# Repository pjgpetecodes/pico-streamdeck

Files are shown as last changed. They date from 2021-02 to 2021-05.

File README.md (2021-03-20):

# Pico Producer

## About this Project

This project is an OBS Controller using a Raspberry Pi Pico and CircuitPython.

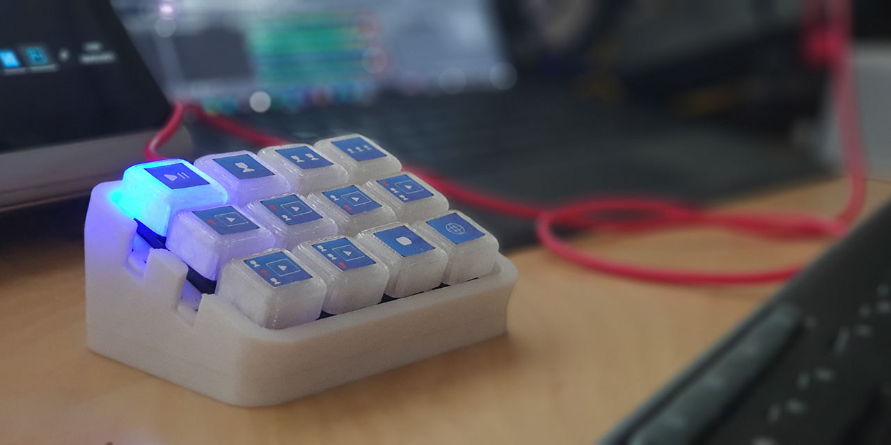
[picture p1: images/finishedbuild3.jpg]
Pico StreamDeck Build 1 Raspberry Pi Pico StreamDeck Build 1


# In Action

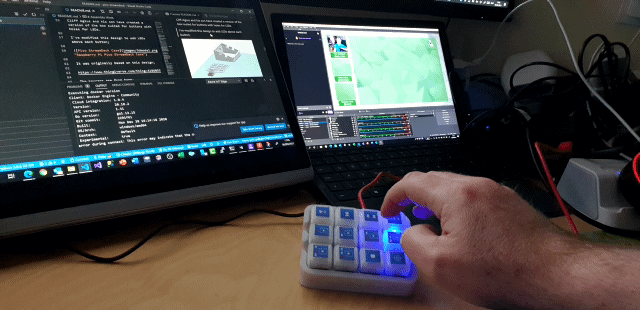
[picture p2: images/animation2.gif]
Pico StreamDeck In Action Raspberry Pi Pico StreamDeck In Action


# Featured

The Raspberry Pi Pico Producer has been featured in the following publications;

- Raspberry Pi Website: https://www.raspberrypi.org/documentation/rp2040/getting-started/
- Hackster: https://www.hackster.io/news/pete-gallagher-s-raspberry-pi-pico-stream-deck-aids-obs-work-via-a-smart-circuitpython-script-0df423724379
- Hackster: https://www.hackster.io/news/use-a-raspberry-pi-pico-to-build-your-own-affordable-stream-deck-a0ad237f0d25
- Hackaday: https://hackaday.com/2021/02/23/lighted-raspberry-pico-stream-deck-is-easy-as-pi/
- OSH Park: https://blog.oshpark.com/2021/03/08/obs-controller-using-circuitpython-on-rpi-pico/

## Basic Circuit

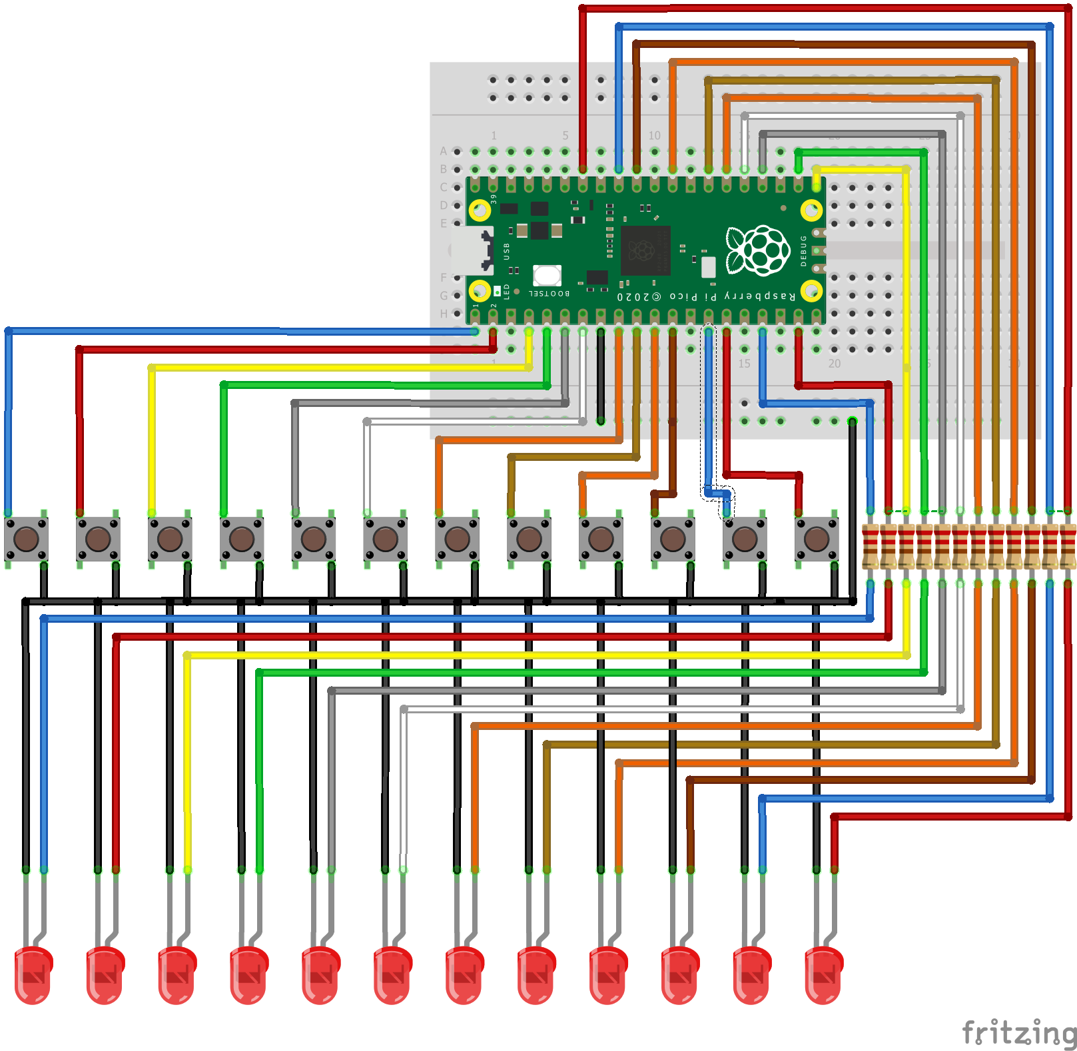
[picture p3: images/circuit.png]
Pico StreamDeck Circuit Raspberry Pi Pico StreamDeck Circuit


I've avoid GP15 as it's assigned a USB function... Using GP15 results in the following error at startup;

"ValueError: GP15 in use"

# PCB

Front

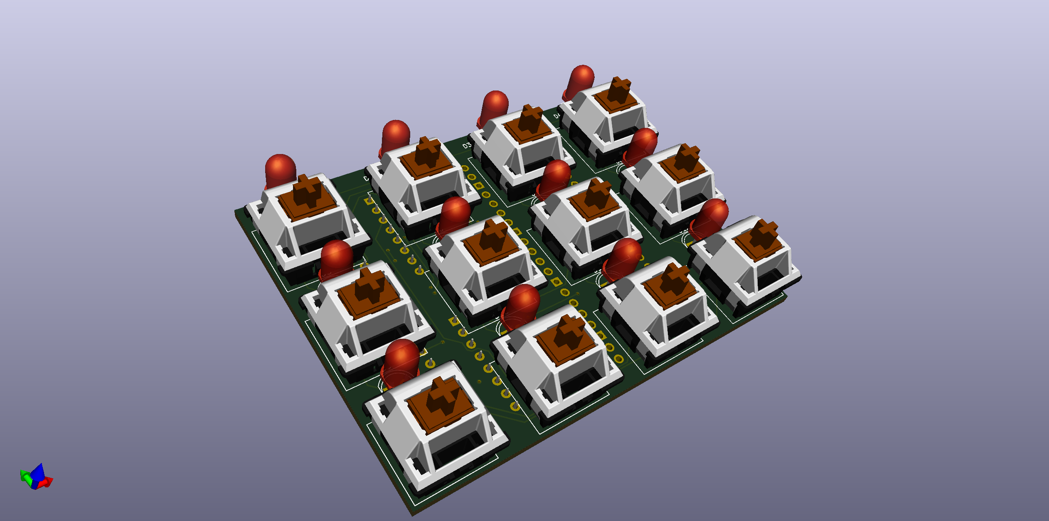
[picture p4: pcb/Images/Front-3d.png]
Pico StreamDeck PCB Front Raspberry Pi Pico StreamDeck PCB - Front


Back

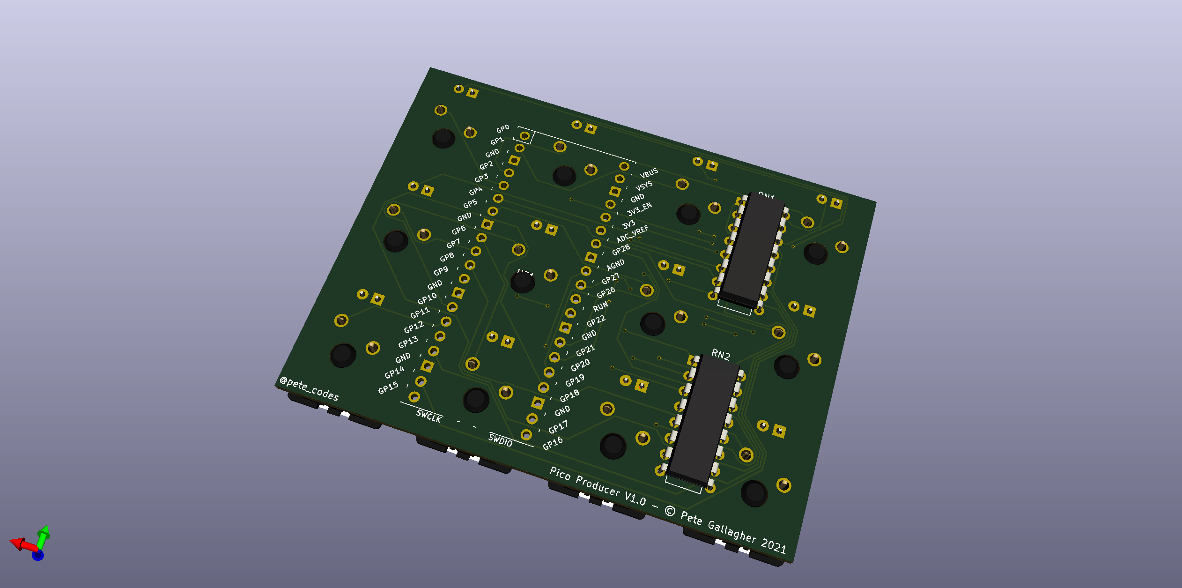
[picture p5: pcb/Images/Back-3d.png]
Pico StreamDeck PCB Back Raspberry Pi Pico StreamDeck PCB - Back


PCB

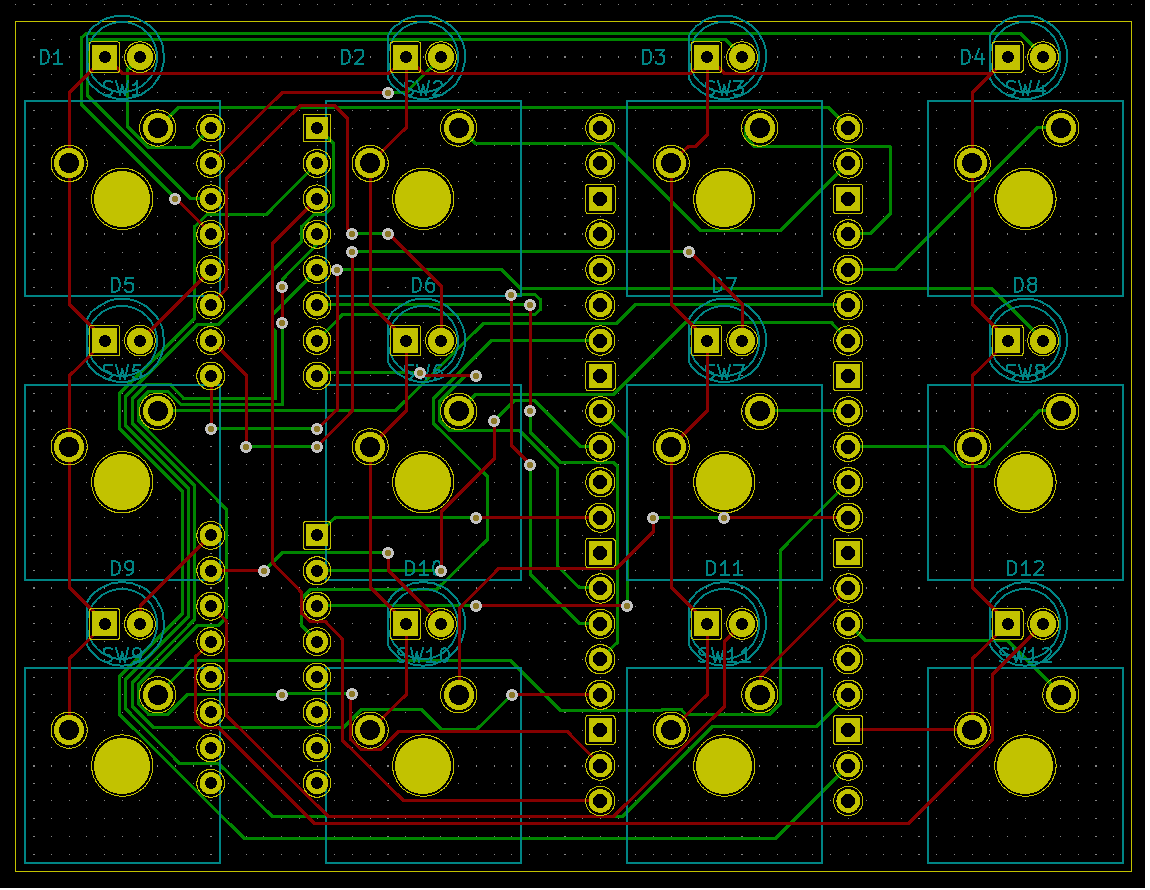
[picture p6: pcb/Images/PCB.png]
Pico StreamDeck PCB PCB Raspberry Pi Pico StreamDeck PCB


You can have your PCB made at OSH Park here;

https://oshpark.com/shared_projects/UNP0qi2U

# Parts List

| Part | Qty | Link |
|---|-----|---|
| PCB | 1 | https://oshpark.com/shared_projects/UNP0qi2U |
| Cherry MX Keycaps | 12 | https://amzn.to/2Oo1nLP |
| 3mm LED | 12 | https://amzn.to/3rAqNEV |
| 220 Ohm 8x Isolated Resistor Pack | 2 | http://bit.ly/picoproducerresistorarray |
| Raspberry Pi Pico | 1 | http://bit.ly/pimoroni-pico |
| 20 pin Male PCB Header | 2 | https://amzn.to/3sUr8lN |
| 3D Printed Case | 1 | https://www.thingiverse.com/thing:4800253 |

Notes: 

- You can feel free to use 12 individual 220 Ohm Resistors - https://amzn.to/3qqaWai
- If you wire this without a PCB then use the following wire from Pimoroni - http://bit.ly/pimoroni-rainbow-wire

# Case

We now have two different case designs....

Cliff Agius and his son have created a version of the box suited for buttons with holes for LEDs.

I've modified this design to add LEDs above each button;

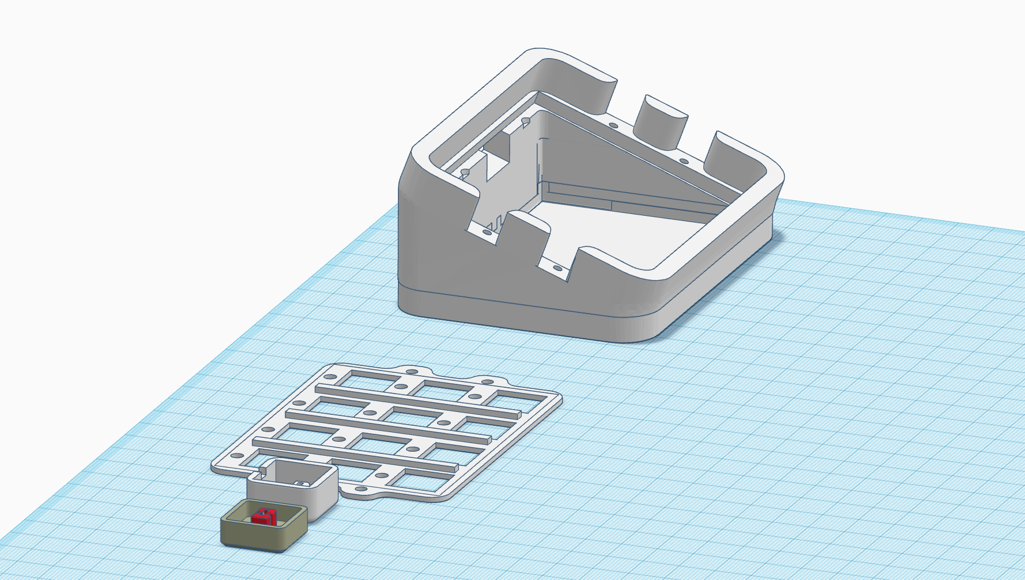
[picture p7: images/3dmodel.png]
Pico StreamDeck Case Raspberry Pi Pico StreamDeck Case


It was originally based on this design;

https://www.thingiverse.com/thing:4186055

The keycaps are from here;

https://www.thingiverse.com/thing:4186055

You can find the project on Thingiverse here;

https://www.thingiverse.com/thing:4800253

# Assembly Hints

- Insert the 20 Pin PCB headers with the long legs away from the PCB towards the Pico (Otherwise it'll fowl the faceplate)
- Solder the 2 Resistor Packs and the Pico PCB Headers first. Then the LEDs and Buttons. Then the Pico.
- You'll need to trim the legs on the resistor packs which border the three left hand buttons.
- Insert the LEDs into the PCB, then insert the Buttons into the faceplate and then insert that into the PCB.
- Push the leds back through the PCB, so they poke into the holes in the faceplate, otherwise they'll be below the faceplate.
- You'll need to trim the legs on the PCB headers otherwise it'll fowl the bottom of the case.

# CircuitPython HID

You can find some more info about the CircuitPython KeyMappings here;

https://circuitpython.readthedocs.io/projects/hid/en/latest/_modules/adafruit_hid/keycode.html

## Instructions

- Plug in the Raspberry Pi Pico while holding the onboard button.
- Your PC will mount the Pico as a drive
- Copy the `adafruit-circuitpython-raspberry_pi_pico-en_US-6.2.0-beta.1.uf2` file to the Pico
- The Pico will reboot once it's done with CircuitPython onboard.
- Copy the `adafruit_hid` folder and the `code.py` file to the Pico
- In OBS setup Hotkeys for the different scenes by putting your cursor in the Hotkey Box and pressing a button...

```
Scene 1 =  ctrl + F1
Scene 2 =  ctrl + F2
Scene 3 =  ctrl + F3
Scene 4 =  ctrl + F4
Scene 5 =  ctrl + F5
Scene 6 =  ctrl + F6
Scene 7 =  ctrl + F7
Scene 8 =  ctrl + F8
Scene 9 =  ctrl + F9
Scene 10 =  ctrl + F10
Scene 11 =  ctrl + F11
Scene 12 =  ctrl + F12
```

- Press the buttons to change scenes in OBS!
- Each button will light a corresponding LED to show which Scene is currently active.

## Debugging

Circuit Python creates a virtual COM port, so you can use a terminal Program set to 8N1 9600 Baud to debug the code... Just hit the enter key at teh prompt, and the terminal will echo there.

It might help to put a large enough delay at the start of your code to give you time to initialise the terminal.

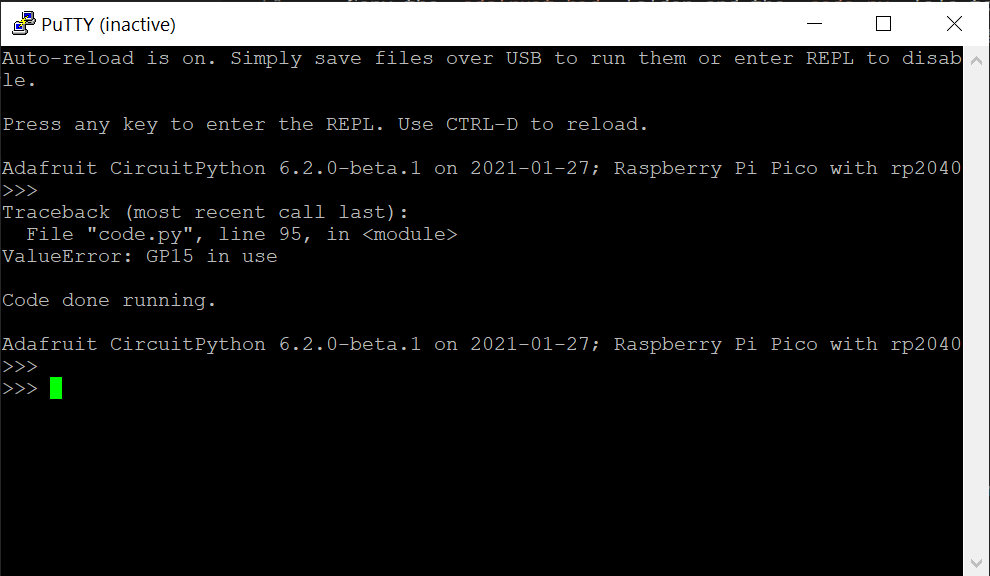
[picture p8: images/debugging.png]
Pico Debugging Raspberry Pi Pico Debugging


## Future Planning

- Look at Bluetooth / WebSockets (Will need add on circuitary!)
- Possible Matrix Input (But, I like the simplicity)
- Possible Resistor Ladder Input (But, again, I like the simplicity)

## Notes

The HID control code is based on a nice blog post by Hriday which shows how to get the Pico working as a HID device, emulating a keyboard;

https://hridaybarot.home.blog/2021/01/31/using-raspberry-pi-pico-has-hid-device-to-control-mouse-and-keyboard/

## Thanks

Thanks to Cliff Agius and his son for the original 3d Files.
Thanks to John Furcean for refactoring the code.
Thanks to frankalicious for fixing some spelling checks.

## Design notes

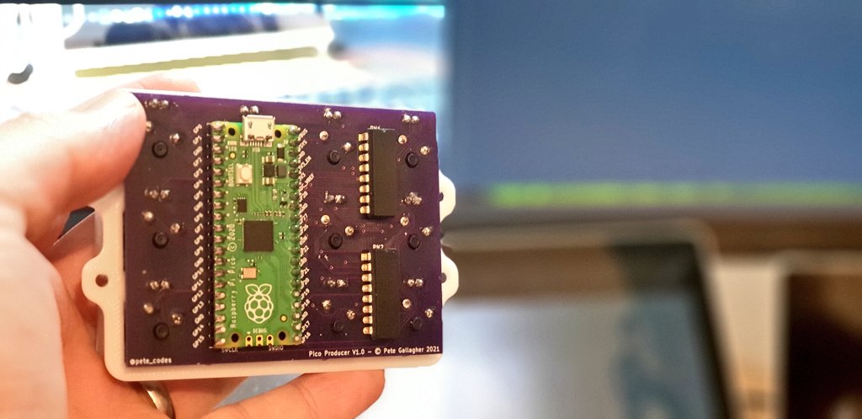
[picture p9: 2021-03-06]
images/pcb_finished1.jpg

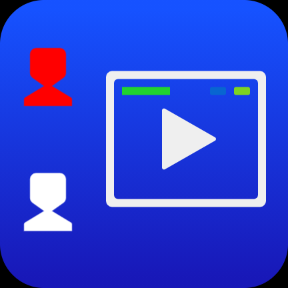
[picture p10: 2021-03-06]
keycaps/2people-topshare(Big).png

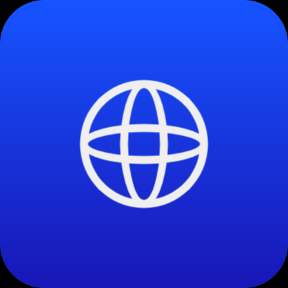
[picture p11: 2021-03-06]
keycaps/link (big).png

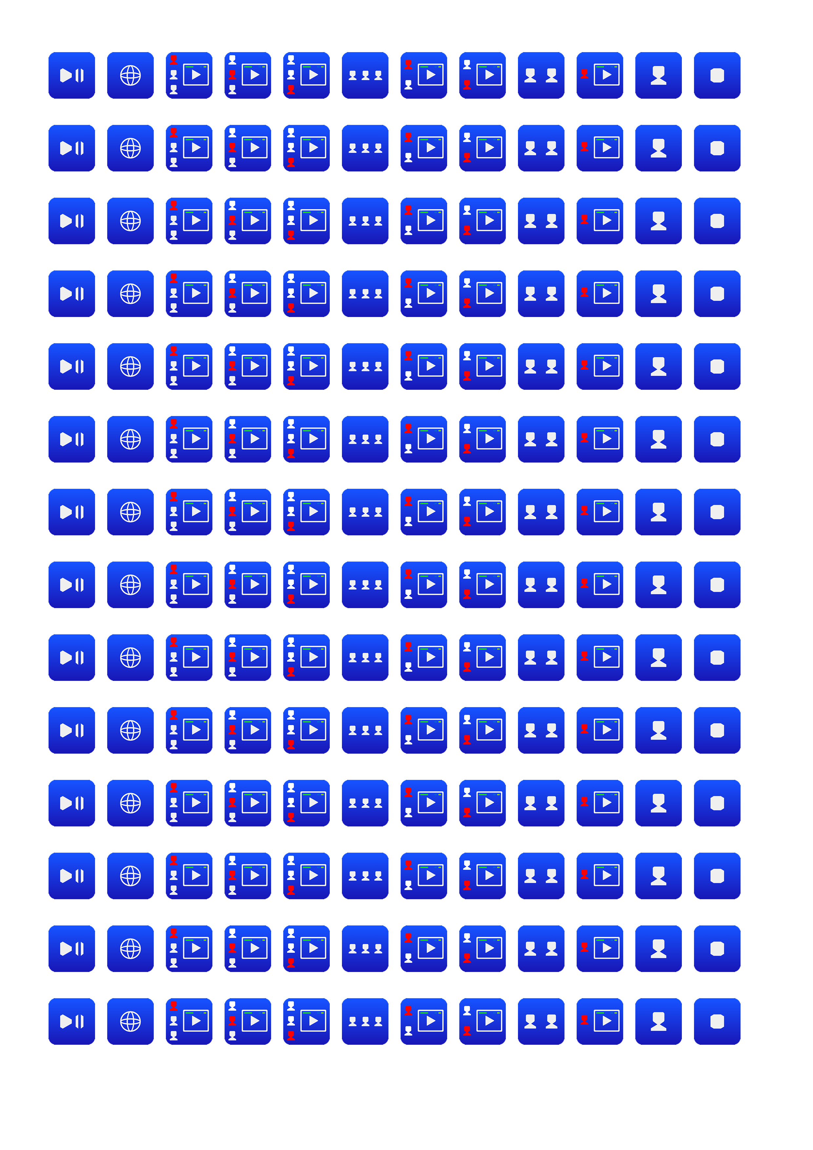
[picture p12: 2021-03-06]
keycaps/KeyCaps-Multiple.png

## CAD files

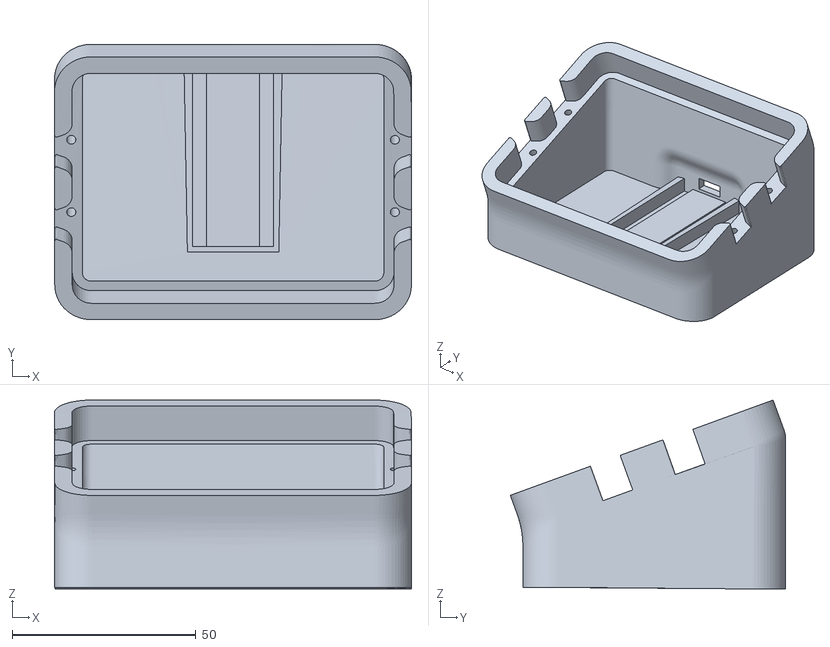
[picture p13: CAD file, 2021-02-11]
3dfiles/MiniMACroKeyboardMainV2.stl
97.1 x 74.9 x 51.4

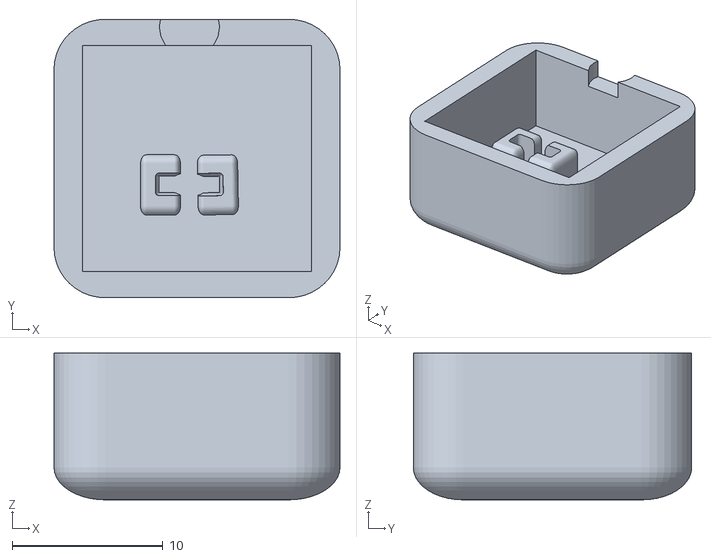
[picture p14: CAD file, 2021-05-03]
3dfiles/Pico Producer 1.5 - Keycap.stl
19.0 x 18.5 x 9.75

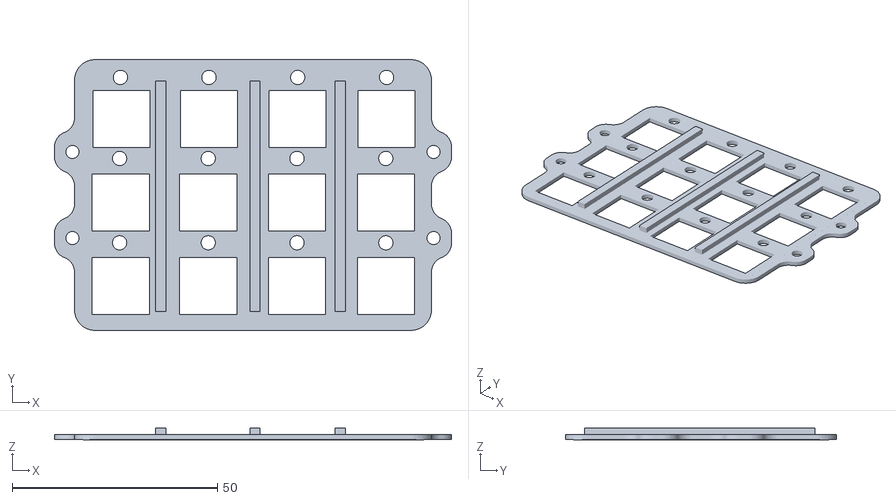
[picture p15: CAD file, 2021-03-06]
3dfiles/Pico Producer 1.5 - Faceplate.stl
96.8 x 66.0 x 3.00

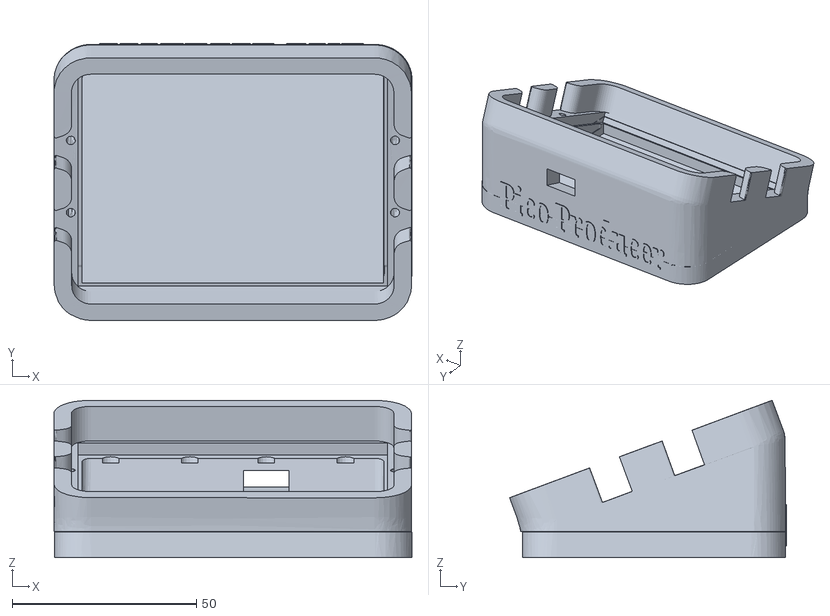
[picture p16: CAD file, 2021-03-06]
3dfiles/Pico Producer 1.5 - Case.stl
97.2 x 75.1 x 42.7

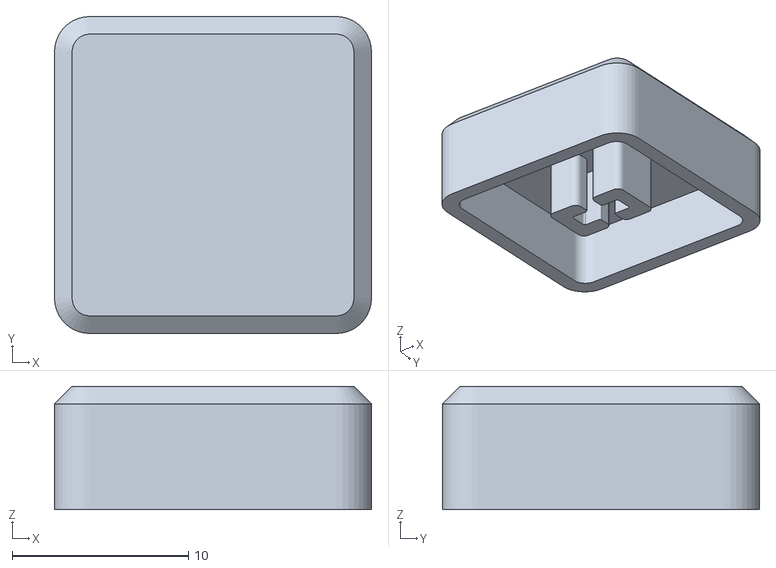
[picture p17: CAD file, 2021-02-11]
3dfiles/Keycap.STL
18.0 x 18.0 x 7.00

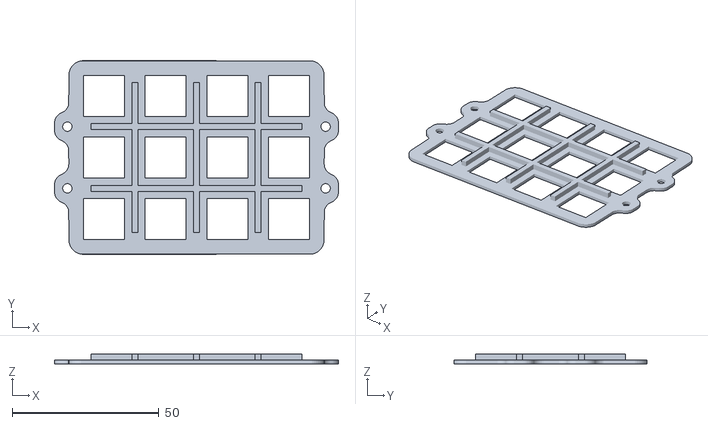
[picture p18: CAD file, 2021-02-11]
3dfiles/MiniMACroKeyboardPanelV2.stl
96.8 x 66.0 x 3.27

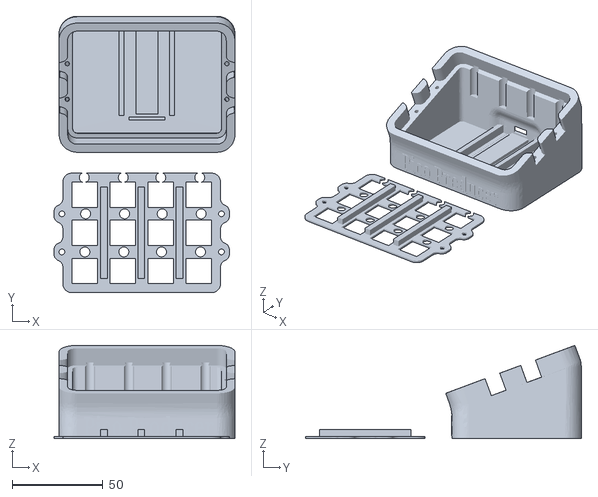
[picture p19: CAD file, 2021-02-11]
3dfiles/Pico Producer 1.0.stl
99.8 x 152.5 x 51.4

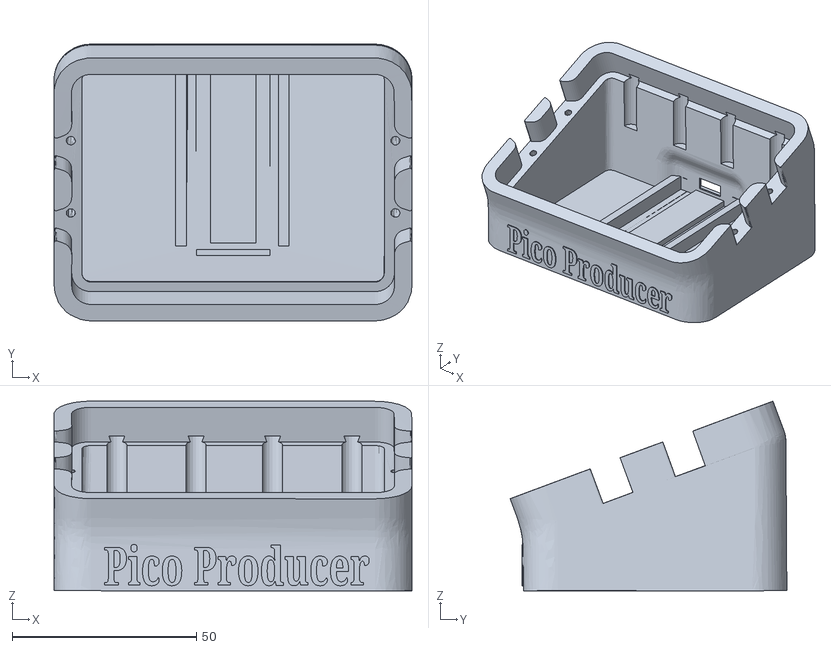
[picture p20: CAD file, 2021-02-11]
3dfiles/Pico Producer 1.0 - Base.stl
97.1 x 75.0 x 51.4

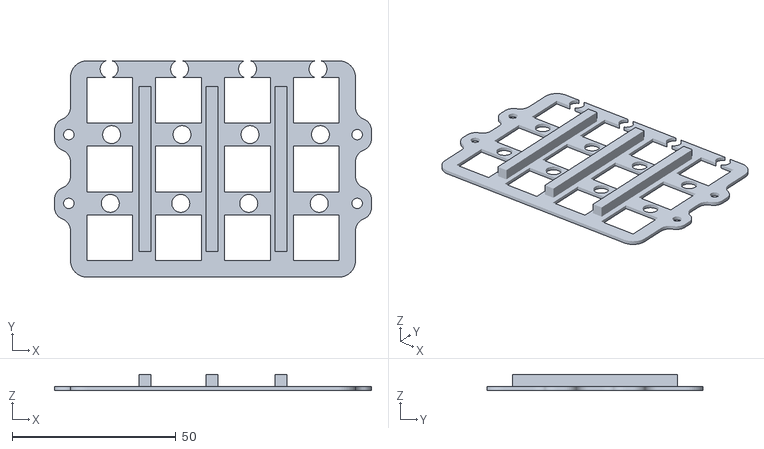
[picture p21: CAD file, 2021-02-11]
3dfiles/Pico Producer 1.0 - FacePlate.stl
96.8 x 66.0 x 4.90

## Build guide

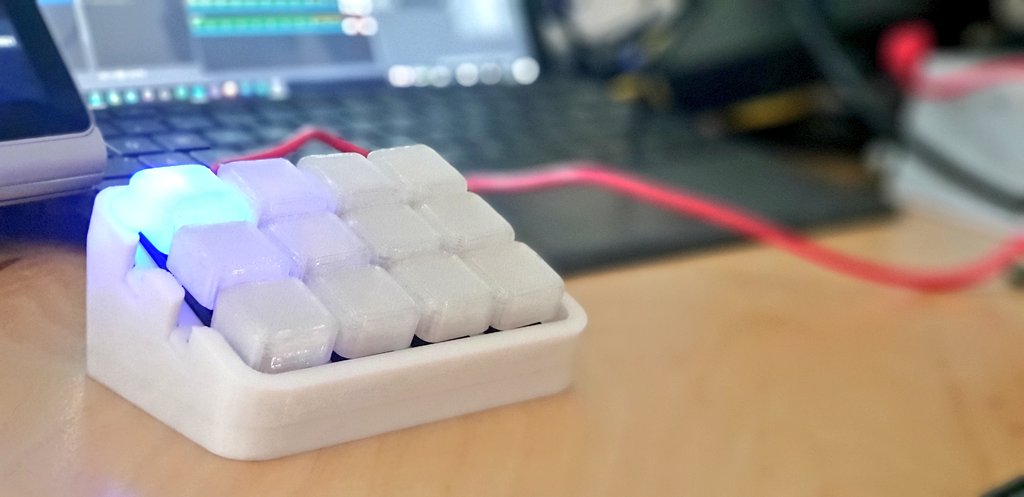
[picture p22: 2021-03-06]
images/FinishedBuild2.jpg

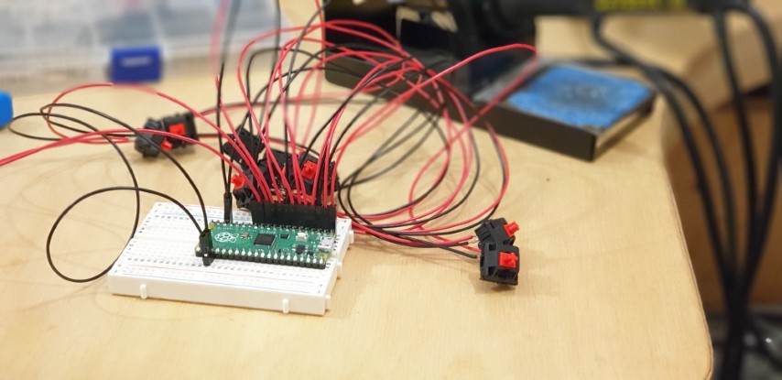
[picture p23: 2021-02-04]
images/build1.jpg

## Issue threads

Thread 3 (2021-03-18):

Code.py seems to be a copy of README.md

starbuck93, 2021-03-18:
Looks like commit 408513ce63ca9fb000175ee4bcce858a3a148454 replaced [code.py](https://github.com/pjgpetecodes/pico-streamdeck/blob/main/code.py) with essentially a copy of README.md. Just booted my Pico up for the first time and it looks like going back in time to paste the merged code.py from https://github.com/pjgpetecodes/pico-streamdeck/commit/7de0eab00ef6f1831614697238b37bae672ed84d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 works fine!

pjgpetecodes, 2021-03-18:
That's a great call! No idea how that happenned! Thanks! Fixed... !

Closed 2021-03-18.

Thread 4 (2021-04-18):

USB port hole is not aligned with Pico on "Pico Producer 1.5 - Case.stl"

Chsbrgr, 2021-04-18:
Hi, My friend and I are working on building a couple of these thanks to the work you did here. We ran into a couple of issues with the 3d print of the case.

One is that the hole for the USB port is not aligned with the Pi Pico if you use the custom printed circuit board as ordered from OSHPark. I estimate that I had to remove about 2 mm of material to the left of the hole (when looking at it from the back), and 1.5 mm of material on the top edge of the hole. you may want to remove even more material, as some micro USB cables have thick boots on the end.

Chsbrgr, 2021-04-18:
I took a photo of the top plate assembled sitting in the case. I think another cause of the top not being aligned is the top plate does not fully seat into the case once assembled.

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

pjgpetecodes, 2021-04-18:
Ooo... Thanks.. I'll have a look! Mega cool that you're making a couple though.... How's everything else?

Chsbrgr, 2021-04-18:
overall, great! the OSHpark PCBs were delivered in about 1.5 weeks (understandably) and worked great. the pico code and setup was easy, and it is also easy to change key-presses just by editing the python file.

pjgpetecodes, 2021-04-18:
That's fab then! Yeah... 3d design is definitely not one of my strong suits... I was bashing changes into Cliff Agius's existing design using tinkercad!

blsmit5728, 2021-05-04:
Can you share the tinker CAD link? or export it? I'd like to adjust a few things.

pjgpetecodes, 2021-05-04:
Of course! https://www.tinkercad.com/things/l5AGCo04b0O

xenonbart, 2023-03-04:
This issue is also present with pico drop-in replacements such as the waveshare RP2040 Plus, which uses USB-C with the additional issue that the hole isn't big enough to accomodate a regular USB-C cable.

wb1016, 2023-12-16:
still not fixed

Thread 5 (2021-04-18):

Small gap between sections in "Pico Producer 1.2 - Case.stl"

Chsbrgr, 2021-04-18:
My friend and I found a couple issues with the 3d print file while trying to build one of these.

One is that there is a small gap between the sections of the base that causes a 3d print slicer to want to insert lots of extra supports, since it thinks the top half is free-floating. We were able to manually fill that gap before printing.

BeauNouvelle, 2022-04-17:
I uploaded mine to an online STL repair tool and after it did its thing, it was able to be sliced correctly.

I also had similar issue with one of the top places having a section filled in after slicing.

This is using Slic3r

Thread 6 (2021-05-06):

Shortcuts to OBS when not in focus?

callimero, 2021-05-06:
Did you have also the problem that OBS does not receive the Keys when not in focus?

My Pico just sends fine keys to OBS, but once I stream/record and using a different app the Keys will not get through anymore.

With a (testcase) second USB keyboard and my old Arduino Mini based Streamdeck I have no problem.

wb1016, 2023-12-16:
can be done with co-software on computer, but implementing it wont be simple.

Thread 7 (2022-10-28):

Hotswappable key switches

xenonbart, 2022-10-28:
It would be really nice if the solder points for the switches support solder pads for hot swap sockets. That way I can swap out switches that break or just switch to a different switch type without having to desolder and resoldering everything.

pjgpetecodes, 2022-10-28:
That's a nice idea!

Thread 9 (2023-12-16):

keycap falls off easily

wb1016, 2023-12-16:
keycap doesnt make a tight fit with switch shaft. thus, falls off easily.

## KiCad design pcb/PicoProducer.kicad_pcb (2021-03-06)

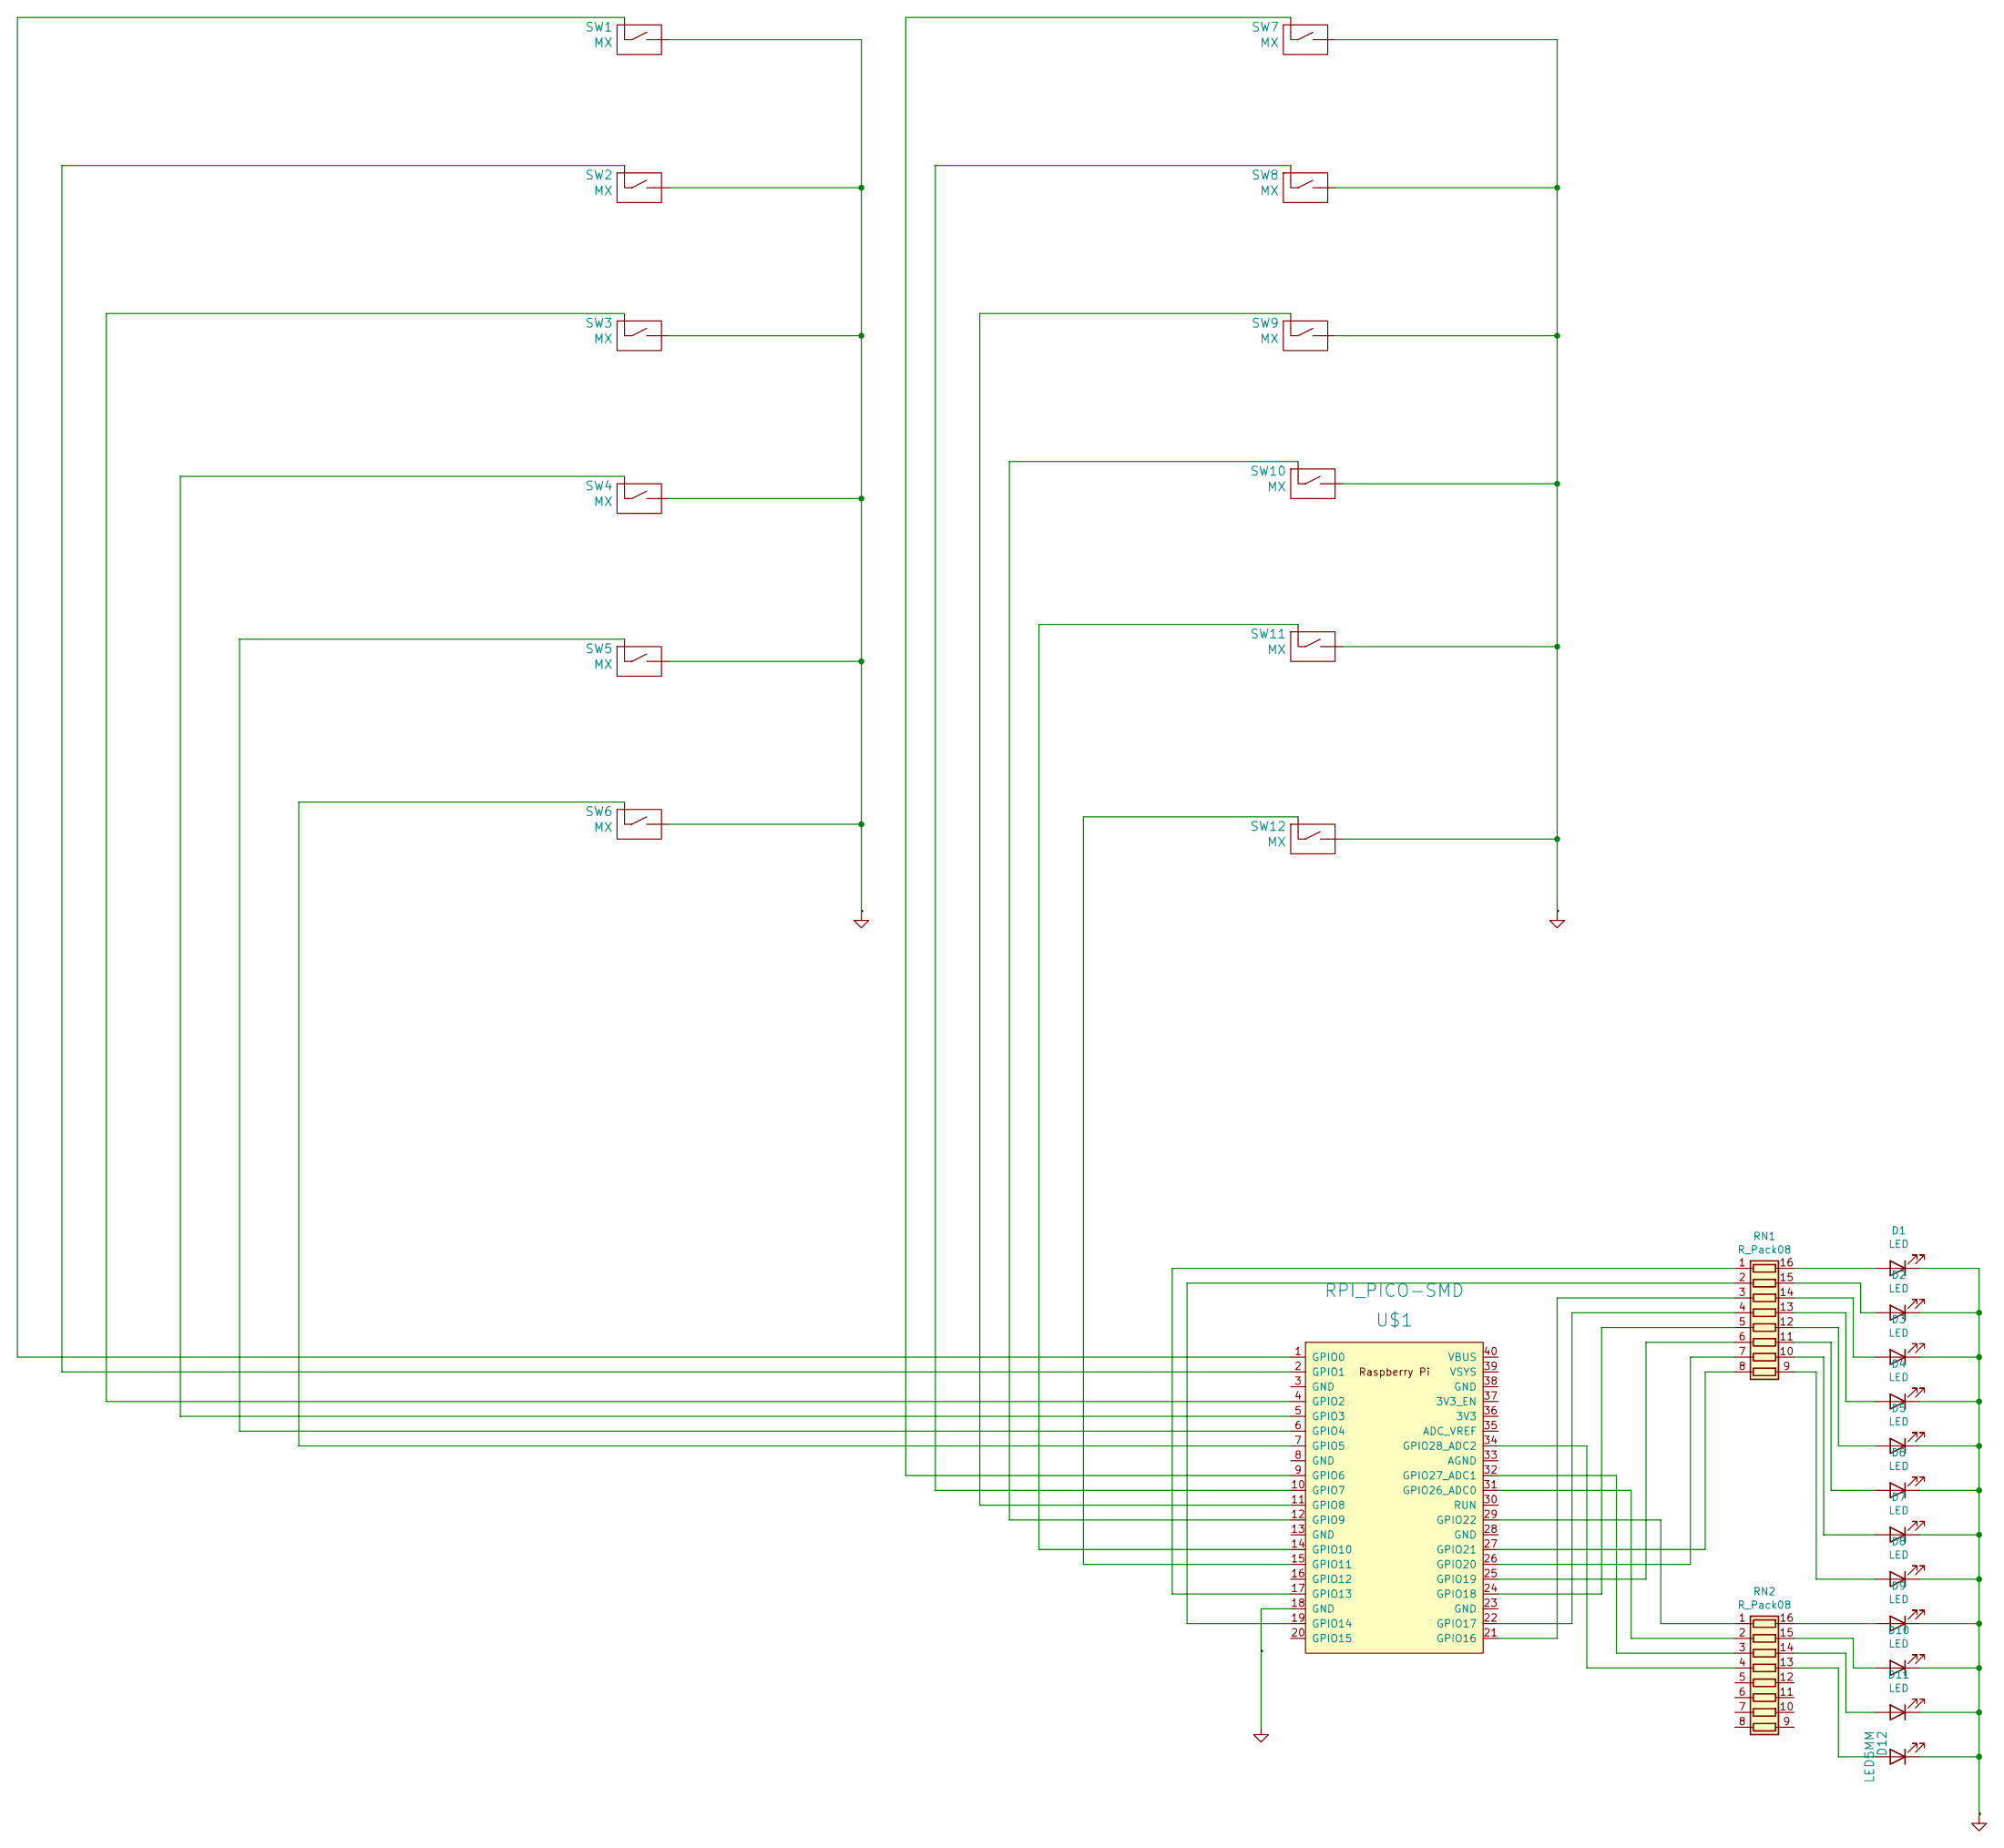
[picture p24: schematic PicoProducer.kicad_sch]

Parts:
D1, D2, D3, D4, D5, D6, D7, D8, D9, D10, D11: LED; LED_D5.0mm
D12: LED5MM; LED_D5.0mm
RN1, RN2: R_Pack08; DIP-16_W7.62mm
SW1, SW3, SW4, SW5, SW6, SW7, SW8, SW9, SW10, SW11, SW12: MX; SW_Cherry_MX_PCB_1.00u
SW2: MX; SW_Cherry_MX_Plate_1.00u
U$1: RPI_PICO-SMD; RPi_Pico_SMD_TH

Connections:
GND: D1.1 (K), D2.1 (K), D3.1 (K), D4.1 (K), D5.1 (K), D6.1 (K), D7.1 (K), D8.1 (K), D9.1 (K), D10.1 (K), D11.1 (K), D12.1 (K), SW1.2 (B), SW2.2 (B), SW3.2 (B), SW4.2 (B), SW5.2 (B), SW6.2 (B), SW7.2 (B), SW8.2 (B), SW9.2 (B), SW10.2 (B), SW11.2 (B), SW12.2 (B), U$1.18 (GND)
unnamed: D1.2 (A), RN1.16 (R1.2)
unnamed: D2.2 (A), RN1.15 (R2.2)
unnamed: D3.2 (A), RN1.14 (R3.2)
unnamed: D4.2 (A), RN1.13 (R4.2)
unnamed: D5.2 (A), RN1.12 (R5.2)
unnamed: D6.2 (A), RN1.11 (R6.2)
unnamed: D7.2 (A), RN1.10 (R7.2)
unnamed: D8.2 (A), RN1.9 (R8.2)
unnamed: D9.2 (A), RN2.16 (R1.2)
unnamed: D10.2 (A), RN2.15 (R2.2)
unnamed: D11.2 (A), RN2.14 (R3.2)
unnamed: D12.2 (A), RN2.13 (R4.2)
unnamed: RN1.1 (R1.1), U$1.17 (GPIO13)
unnamed: RN1.2 (R2.1), U$1.19 (GPIO14)
unnamed: RN1.3 (R3.1), U$1.21 (GPIO16)
unnamed: RN1.4 (R4.1), U$1.22 (GPIO17)
unnamed: RN1.5 (R5.1), U$1.24 (GPIO18)
unnamed: RN1.6 (R6.1), U$1.25 (GPIO19)
unnamed: RN1.7 (R7.1), U$1.26 (GPIO20)
unnamed: RN1.8 (R8.1), U$1.27 (GPIO21)
unnamed: RN2.1 (R1.1), U$1.29 (GPIO22)
unnamed: RN2.2 (R2.1), U$1.31 (GPIO26_ADC0)
unnamed: RN2.3 (R3.1), U$1.32 (GPIO27_ADC1)
unnamed: RN2.4 (R4.1), U$1.34 (GPIO28_ADC2)
unnamed: SW1.1 (A), U$1.1 (GPIO0)
unnamed: SW2.1 (A), U$1.2 (GPIO1)
unnamed: SW3.1 (A), U$1.4 (GPIO2)
unnamed: SW4.1 (A), U$1.5 (GPIO3)
unnamed: SW5.1 (A), U$1.6 (GPIO4)
unnamed: SW6.1 (A), U$1.7 (GPIO5)
unnamed: SW7.1 (A), U$1.9 (GPIO6)
unnamed: SW8.1 (A), U$1.10 (GPIO7)
unnamed: SW9.1 (A), U$1.11 (GPIO8)
unnamed: SW10.1 (A), U$1.12 (GPIO9)
unnamed: SW11.1 (A), U$1.14 (GPIO10)
unnamed: SW12.1 (A), U$1.15 (GPIO11)

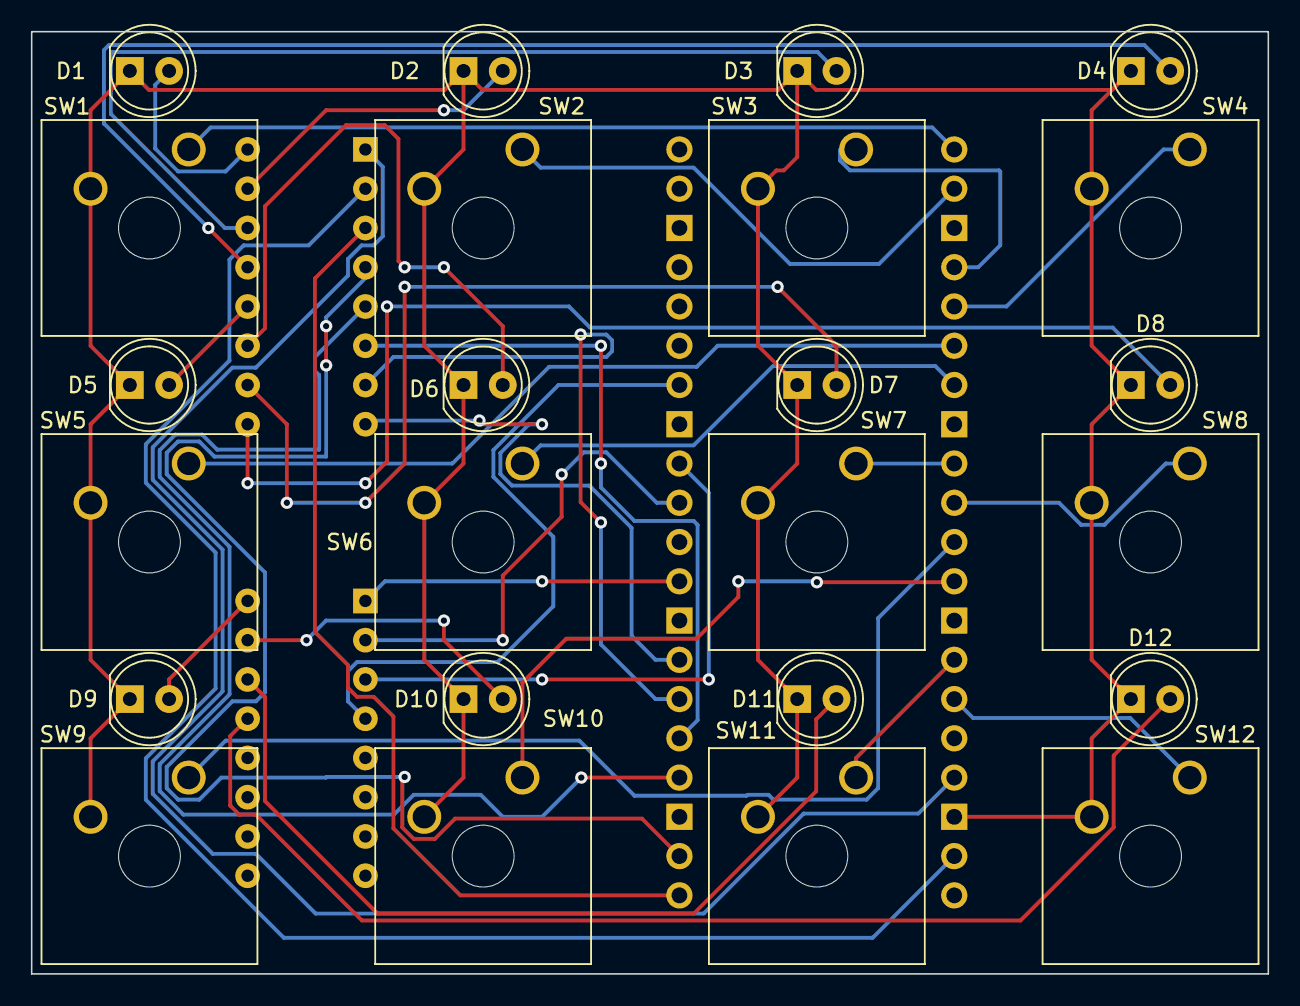
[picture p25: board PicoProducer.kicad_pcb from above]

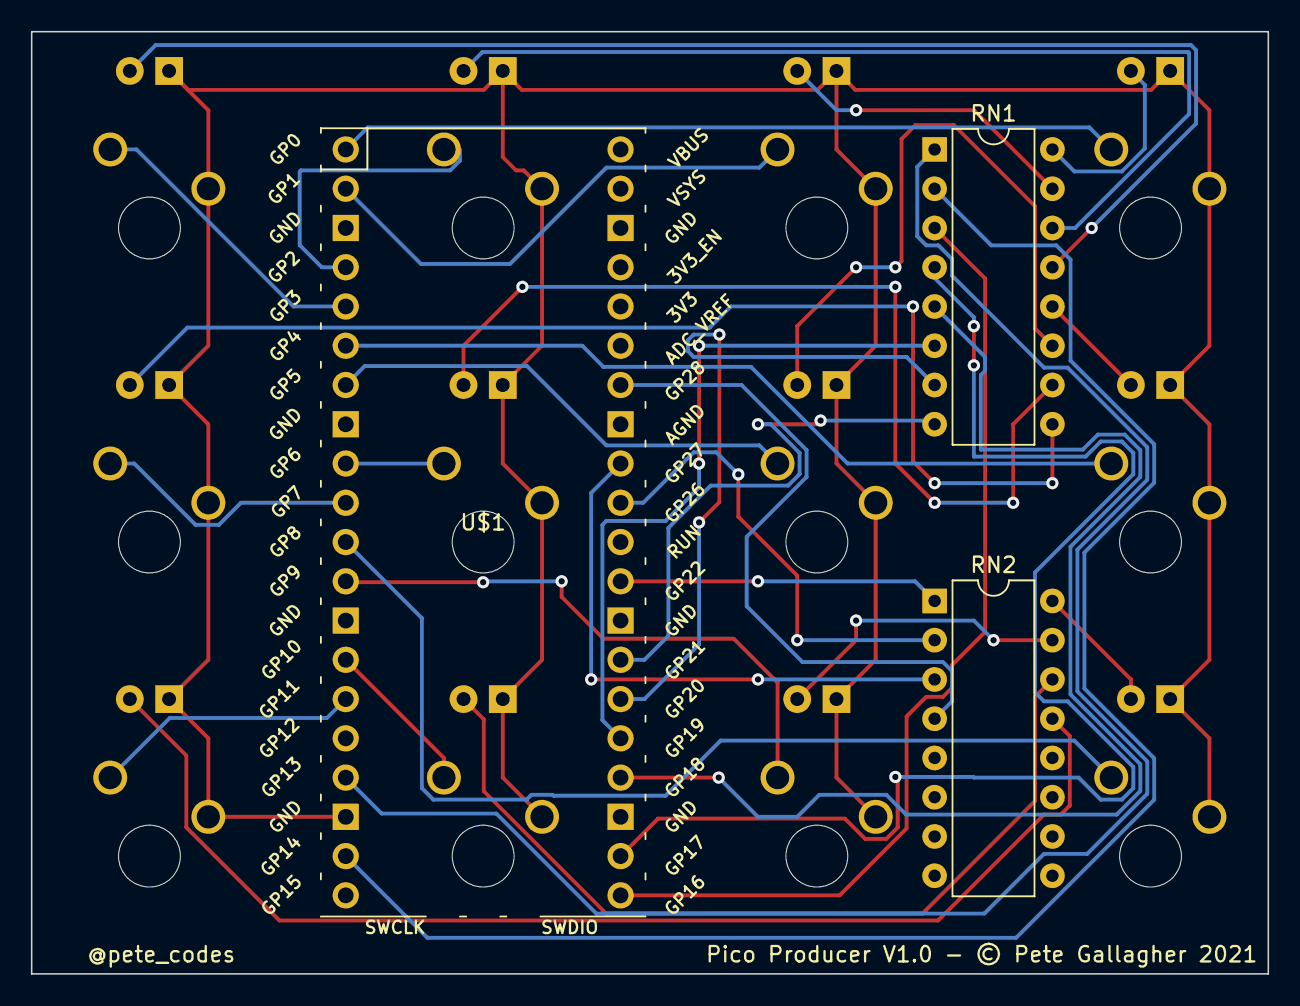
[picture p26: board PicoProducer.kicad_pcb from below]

Board: 2 copper layers, 80.0 x 61.0 mm, 27 parts (3 on the bottom side), 37 nets.

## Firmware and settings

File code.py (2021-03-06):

#####################################################
#                                                   #
#           Raspberry Pi Pico Producer              #
#                                                   #
#         Developed by Pete Gallagher 2021          #
#                                                   #
#####################################################

# Author:   Pete Gallagher
# Version:  1.0
# Date:     11th February 2021
# Twitter:  https://www.twitter.com/pete_codes
# Blog:     https://www.petecodes.co.uk

# Imports
import time
import usb_hid
import board

from digitalio import DigitalInOut, Direction, Pull
from adafruit_hid.keyboard import Keyboard
from adafruit_hid.keycode import Keycode

# Initialize Keybaord
keyboard = Keyboard(usb_hid.devices)

# Define HID Key Output Actions
hid_actions = [
    {
        "name": "Scene 1",
        "held": False,
        "keycode": (Keycode.CONTROL, Keycode.F1),
        "button": None,
        "led": None,
    },
    {
        "name": "Scene 2",
        "held": False,
        "keycode": (Keycode.CONTROL, Keycode.F2),
        "button": None,
        "led": None,
    },
    {
        "name": "Scene 3",
        "held": False,
        "keycode": (Keycode.CONTROL, Keycode.F3),
        "button": None,
        "led": None,
    },
    {
        "name": "Scene 4",
        "held": False,
        "keycode": (Keycode.CONTROL, Keycode.F4),
        "button": None,
        "led": None,
    },
    {
        "name": "Scene 5",
        "held": False,
        "keycode": (Keycode.CONTROL, Keycode.F5),
        "button": None,
        "led": None,
    },
    {
        "name": "Scene 6",
        "held": False,
        "keycode": (Keycode.CONTROL, Keycode.F6),
        "button": None,
        "led": None,
    },
    {
        "name": "Scene 7",
        "held": False,
        "keycode": (Keycode.CONTROL, Keycode.F7),
        "button": None,
        "led": None,
    },
    {
        "name": "Scene 8",
        "held": False,
        "keycode": (Keycode.CONTROL, Keycode.F8),
        "button": None,
        "led": None,
    },
    {
        "name": "Scene 9",
        "held": False,
        "keycode": (Keycode.CONTROL, Keycode.F9),
        "button": None,
        "led": None,
    },
    {
        "name": "Scene 10",
        "held": False,
        "keycode": (Keycode.CONTROL, Keycode.F10),
        "button": None,
        "led": None,
    },
    {
        "name": "Scene 11",
        "held": False,
        "keycode": (Keycode.CONTROL, Keycode.F11),
        "button": None,
        "led": None,
    },
    {
        "name": "Scene 12",
        "held": False,
        "keycode": (Keycode.CONTROL, Keycode.F12),
        "button": None,
        "led": None,
    },
]


# Define button pins
btn_pins = [
    board.GP0,
    board.GP1,
    board.GP2,
    board.GP3,
    board.GP4,
    board.GP5,
    board.GP6,
    board.GP7,
    board.GP8,
    board.GP9,
    board.GP10,
    board.GP11,
]

# Define led pins
led_pins = [
    board.GP13,
    board.GP14,
    board.GP16,
    board.GP17,
    board.GP18,
    board.GP19,
    board.GP20,
    board.GP21,
    board.GP22,
    board.GP26,
    board.GP27,
    board.GP28,
]

# Setup all Buttons as Inputs with PullUps
# Setup all LEDs
for i in range(12):
    button = DigitalInOut(btn_pins[i])
    button.direction = Direction.INPUT
    button.pull = Pull.UP
    hid_actions[i]["button"] = button

    led = DigitalInOut(led_pins[i])
    led.direction = Direction.OUTPUT
    hid_actions[i]["led"] = led


# Loop around and check for key presses
while True:

    for i in range(12):

        # check if button is pressed but make sure it is not held down
        if not hid_actions[i]["button"].value and not hid_actions[i]["held"]:

            # print the name of the command for debug purposes
            print(hid_actions[i]["name"])

            # send the keyboard commands
            keyboard.send(*hid_actions[i]["keycode"])

            # light up the associated LED
            hid_actions[i]["led"].value = True

            # turn off other LEDs that may be on
            for j in range(12):
                if i != j:
                    hid_actions[j]["led"].value = False

            # set the held to True for debounce
            hid_actions[i]["held"] = True

        # remove the held indication if it is no longer held
        elif hid_actions[i]["button"].value and hid_actions[i]["held"]:
            hid_actions[i]["held"] = False

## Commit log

2021-02-04 Added image and circuit
2021-02-06 Added crude LED Control to each button
2021-02-08 Added Extra Buttons and delay between Press and Release
2021-02-08 Added and Updated Circuit
    [Pico StreamDeck.fzz]
2021-02-08 Updated Circuit Colours
    [Pico StreamDeck.fzz]
2021-02-11 Added extra buttons and LEDs
2021-02-11 LED 3d Files added
    [Pico Producer 1.0 - Base.stl, Pico Producer 1.0 - FacePlate.stl, Pico Producer 1.0.stl]
2021-02-11 Switched to Embossed Logo
    [Pico Producer 1.0 - Base.stl, Pico Producer 1.0 - FacePlate.stl, Pico Producer 1.0.stl]
2021-02-11 Added Cliff's 3D Files
    [MiniMACroKeyboardMainV2.stl, MiniMACroKeyboardPanelV2.stl]
2021-02-11 Added KeyCaps
    [Keycap.STL]
2021-02-12 Don't use Pin15 - USB Conflict! "ValueError: GP15 in use"
    [Pico StreamDeck.fzz]
2021-02-12 Added extra buttons and LEDs to Circuit
    [Pico StreamDeck.fzz]
2021-02-12 switch from keyboard.send to keyboard.press and keyboard.release
2021-02-12 switch keycodes to using ALT + F1-12
2021-02-12 Added new Finished project and decals
    [Pico StreamDeck.fzz]
2021-03-06 Added PCB, latest Circuit, Code and Key Decals
    [Pico Producer 1.5 - Case.stl, Pico Producer 1.5 - Faceplate.stl, Pico Producer 1.5 - Keycap.stl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]
2021-03-06 Add Parts List and Assembly hints to Readme
2021-03-18 Fix issue with code.py
    [code.py]
2021-03-20 Added PCB and Case Links
2021-05-03 Reduced size of keycap to prevent catching
    [Pico Producer 1.5 - Keycap.stl]

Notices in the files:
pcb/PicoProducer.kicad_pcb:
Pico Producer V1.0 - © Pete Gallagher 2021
